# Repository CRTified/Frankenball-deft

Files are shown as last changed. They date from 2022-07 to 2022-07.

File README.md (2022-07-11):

# Frankenball-deft

This project is a replacement PCB for the Elecom Deft (non-pro) trackball.
Besides the basic functionality, it exposes two additional GPIO pins 
(also usable for debugging) and is powered by QMK (TODO) on an STM32F411.

The sensor used in the Elecom deft is an PWM3320.

Some additional soldering is required. 
The PCB is intended for SMT assembly by JLCPCB. 
The only extended part is the STM32F411, every other part is a basic component.

## Additional componens used

 - 0.5mm 6pin Clamshell FFC connector (PWM3320 Sensor)
   - https://aliexpress.com/item/1005003981823532.html
 - 0.5mm 12pin Clamshell FFC connector (Side button daughterboard)
   - https://aliexpress.com/item/1005003981823532.html
 - 4 pin JST ZH header (1.5mm pitch) (M1/M2/M3 daughterboard)
   - https://aliexpress.com/item/32763788431.html
 - 51146 Socket (USB connection)
   - https://aliexpress.com/item/4000818221650.html
 - Microswitch (Right mouse button)
   - https://aliexpress.com/item/4000682779339.html
   - https://aliexpress.com/item/4000555763322.html

## Rendered PCB

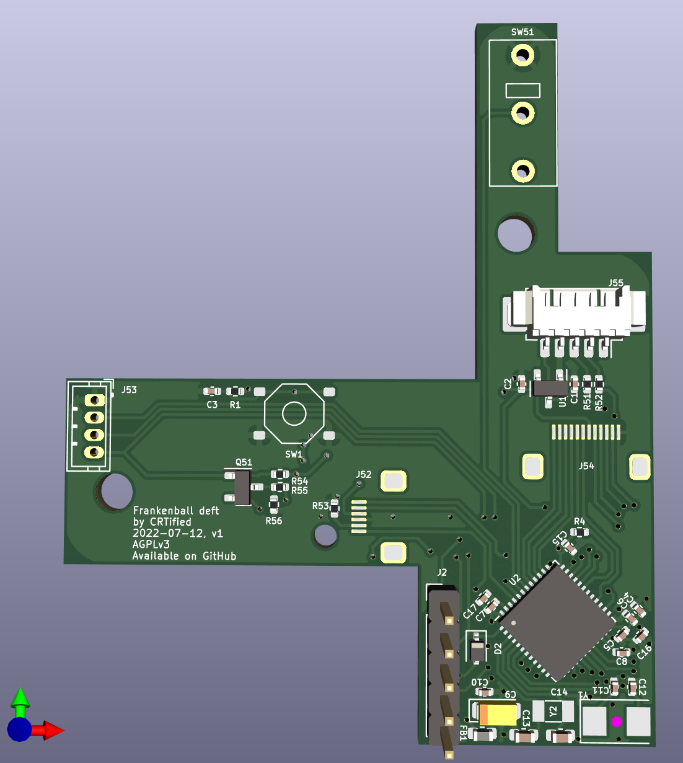
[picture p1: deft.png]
Rendered PCB


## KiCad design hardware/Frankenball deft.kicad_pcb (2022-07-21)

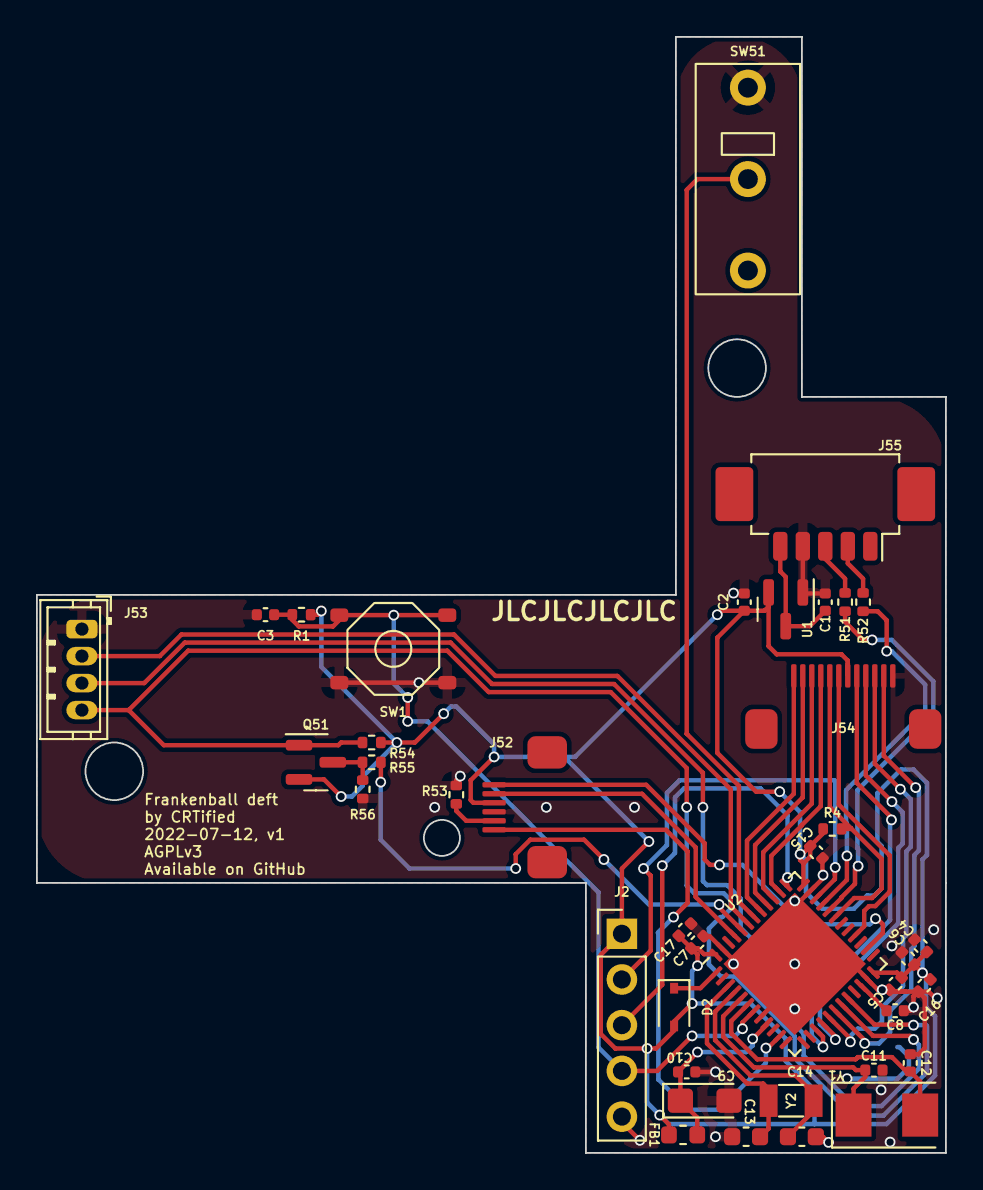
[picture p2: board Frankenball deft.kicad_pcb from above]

Board: 2 copper layers, 50.5 x 62.0 mm, 39 parts (0 on the bottom side), 37 nets.

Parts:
C1, C2: 1µF; C_0402_1005Metric
C3, C4, C5, C6, C7, C10, C15, C16: 100nF; C_0402_1005Metric
C8: 4.7µF; C_0402_1005Metric
C9: 10µF; CP_EIA-3216-10_Kemet-I
C11, C12: 22pF; C_0402_1005Metric
C13, C14: 10pF; C_0603_1608Metric
C17: 4.7uF; C_0402_1005Metric
D2: D_Schottky; D_SOD-323
FB1: 600Ω@100MHz; L_0603_1608Metric
J2: Connector_Generic:Conn_01x05; PinHeader_1x05_P2.54mm_Vertical
J52: PWM3320; FFC Clamshell 0.5mm 6P
J53: Conn_01x04_Male; JST_ZH_B4B-ZR_1x04_P1.50mm_Vertical
J54: Conn_01x12; FFC Clamshell 0.5mm 12P
J55: Conn_01x05_Female; Molex_PicoBlade_53261-0571_1x05-1MP_P1.25mm_Horizontal
Q51: AO3401A; SOT-23
R1: 22kΩ; R_0402_1005Metric
R4: 100k; R_0402_1005Metric
R51, R52: 100Ω; R_0402_1005Metric
R53, R54, R55, R56: 10k; R_0402_1005Metric
SW1: SW_Push; TS-1187A-B-A-B
SW51: SW_Push; Mouse Microswitch SPDT
U1: XC6206PxxxMR; SOT-23
U2: STM32F411CCUx; QFN-48-1EP_7x7mm_P0.5mm_EP5.6x5.6mm
Y1: 8MHz; Crystal_SMD_5032-2Pin_5.0x3.2mm
Y2: 32.768kHz; Crystal_SMD_3215-2Pin_3.2x1.5mm

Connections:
+3.3V: C2.1, C4.1, C5.1, C6.1, C7.1, C15.1, C16.1, C17.1, D2.2 (A), FB1.1, J2.1, J52.4, J54.7, Q51.2 (S), R1.1, R4.2, R54.2, U1.2 (VO), U2.24 (VDD), U2.36 (VDD), U2.48 (VDD)
/BOOT0: R55.1, U2.44 (BOOT0)
/STM32F411/PA1: J52.1, U2.11 (PA1)
/STM32F411/PA5: J54.8, U2.15 (PA5)
/STM32F411/PA6: J54.9, U2.16 (PA6)
/STM32F411/PA7: J54.10, U2.17 (PA7)
/STM32F411/PA10: J54.5, R4.1, U2.31 (PA10)
/STM32F411/PA11: R51.1, U2.32 (PA11)
/STM32F411/PA12: R52.1, U2.33 (PA12)
/STM32F411/PA13: J2.2, U2.34 (PA13)
/STM32F411/PA14: J2.3, U2.37 (PA14)
/STM32F411/PA15: J54.4, U2.38 (PA15)
/STM32F411/PB0: J54.11, U2.18 (PB0)
/STM32F411/PB1: J53.3, U2.19 (PB1)
/STM32F411/PB2: J53.4, Q51.1 (G), R54.1, U2.20 (PB2)
/STM32F411/PB3: J54.3, U2.39 (PB3)
/STM32F411/PB4: J54.2, U2.40 (PB4)
/STM32F411/PB5: J54.1, U2.41 (PB5)
/STM32F411/PB6: SW51.3 (C), U2.42 (PB6)
/STM32F411/PB7: J53.2, U2.43 (PB7)
/STM32F411/PB8: J52.5, U2.45 (PB8)
/STM32F411/PBu13: J52.6, U2.26 (PB13)
/STM32F411/PBu15: J54.6, U2.28 (PB15)
/STM32F411/VBAT_{I}: D2.1 (K), U2.1 (VBAT)
/STM32F411/VREF+: C9.1, C10.1, FB1.2, U2.9 (VDDA)
/STM32F411/XTAL_8M_1: C11.1, U2.5 (PH0), Y1.1
/STM32F411/XTAL_8M_2: C12.1, U2.6 (PH1), Y1.2
/STM32F411/XTAL_32K_1: C13.1, U2.3 (PC14), Y2.1
/STM32F411/XTAL_32K_2: C14.1, U2.4 (PC15), Y2.2
/STM32F411/~RST_{I}: C3.1, J2.4, R1.2, SW1.2, U2.7 (NRST)
/USB_DM: J55.3, R51.2
/USB_DP: J55.2, R52.2
/~CS: J52.2, R53.2
GND: C1.2, C2.2, C3.2, C4.2, C5.2, C6.2, C7.2, C8.2, C9.2, C10.2, C11.2, C12.2, C13.2, C14.2, C15.2, C16.2, C17.2, J2.5, J52.3, J53.1, J54.12, J55.4, R53.1, R56.1, SW1.1, SW51.2 (B), U1.1 (GND), U2.8 (VSSA), U2.23 (VSS), U2.35 (VSS), U2.47 (VSS), U2.49 (VSS)
unnamed: C8.1, U2.22 (VCAP1)
unnamed: Q51.3 (D), R55.2, R56.2
VCC: C1.1, J55.5, U1.3 (VI)

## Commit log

2022-06-23 Initial Schematics commit
    [Frankenball deft.kicad_pcb, Frankenball deft.kicad_sch]
2022-07-11 Am I done?
    [Frankenball deft.kicad_pcb, Frankenball deft.kicad_sch]
2022-07-11 Replace boot config header with PFET
    [Frankenball deft.kicad_pcb, Frankenball deft.kicad_sch]
2022-07-18 Update symbol
    [Frankenball deft.kicad_sch]
2022-07-21 Add fabrication files
    [Frankenball deft.kicad_pcb]

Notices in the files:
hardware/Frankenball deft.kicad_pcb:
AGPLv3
